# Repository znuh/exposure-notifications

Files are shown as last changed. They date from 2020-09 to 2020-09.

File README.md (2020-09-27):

# Exposure Notifications
Printed Circuit Boards for the Covid-19 Exposure Notifications Visualizer - 
[see this for more details](https://znu.nz/exposure_notifications-en)

To remake Exposure Notifications you need to get/make four things:
- a BBC micro:bit or Calliope Mini with the [microbit-corona-scanner](https://github.com/znuh/microbit-corona-scanner) installed
- a black 23x23cm RIBBA frame from IKEA
- the printed circuit board for the LEDs - see the leds/ directory of this repository
- the printed circuit board for the LED matrix controller - **either** matrixctl-v1 **OR** matrixctl-v2
  - matrixctl-v2 includes a socket for the micro:bit and a switching voltage regulator
  - matrixctl-v1 comes without a socket for the micro:bit and has no switching voltage regulator
  - v2 is more efficient and keeps the LED matrix driver cooler when more LEDs light up - therefore I recommend using v2

The printed circuit board designs are made with a **Nightly Development Build** of [KiCAD](https://kicad-pcb.org/).
If you want to open/edit them you also need a recent Nightly Development Build. If you just want to use the PCBs unmodified you can also use the gerber-files from the gerber-subdirectories.

## LED matrix board
The LED matrix board uses Würth 150141RV73100 LEDs. These are bicolor-LEDs but only the red LED is used.
The landing pads for the LEDs have been reduced to a minimum to hide the pads underneath the LEDs. All PCB tracks are on the back side of the PCB. 1206 0-Ohms resistors are used instead of vias to cross tracks.
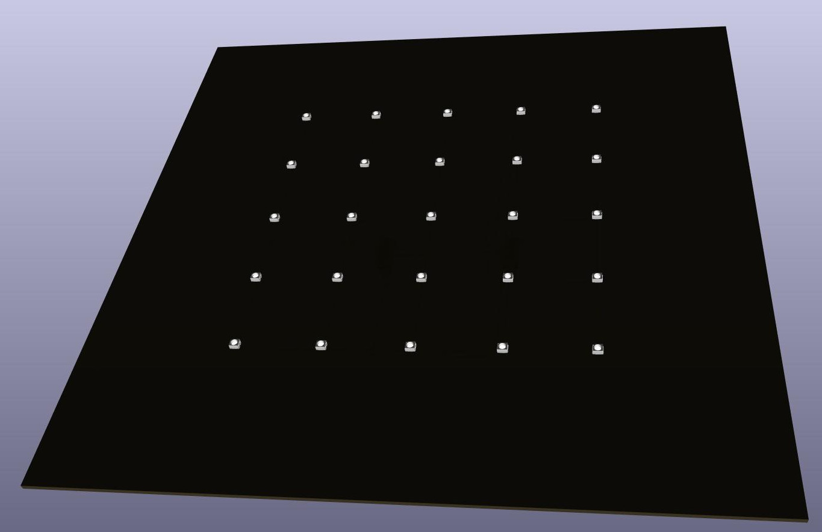
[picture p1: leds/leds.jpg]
LED matrix front side

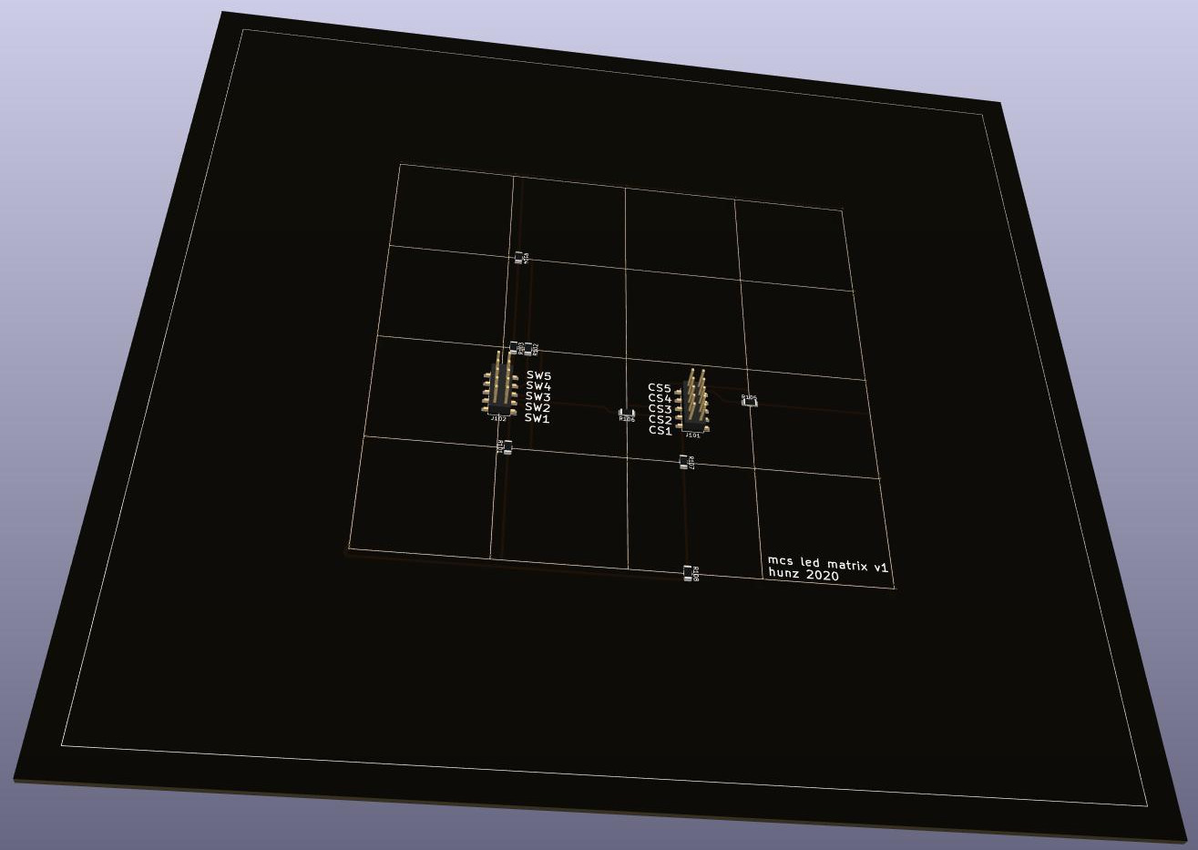
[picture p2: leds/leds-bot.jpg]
LED matrix back side


## matrixctl v2 board ##
The part number of the micro:bit socket is PIS-1240. The Micro-USB connector is a Molex 105017-0001. You can get these parts and all additional components from digi-key.

Following a recommendation from the IS31FL3738 datasheet the board includes a Tantalum Capacitor to avoid audible noise produced by ceramics capacitors through the [piezoelectric effect](https://product.tdk.com/en/contact/faq/31_singing_capacitors_piezoelectric_effect.pdf). Tantalum is a conflict resource. I've chosen a Kemet T495B336K010ATE450 because Kemet is a sane choice in general and their handling of the issue sounds ok.
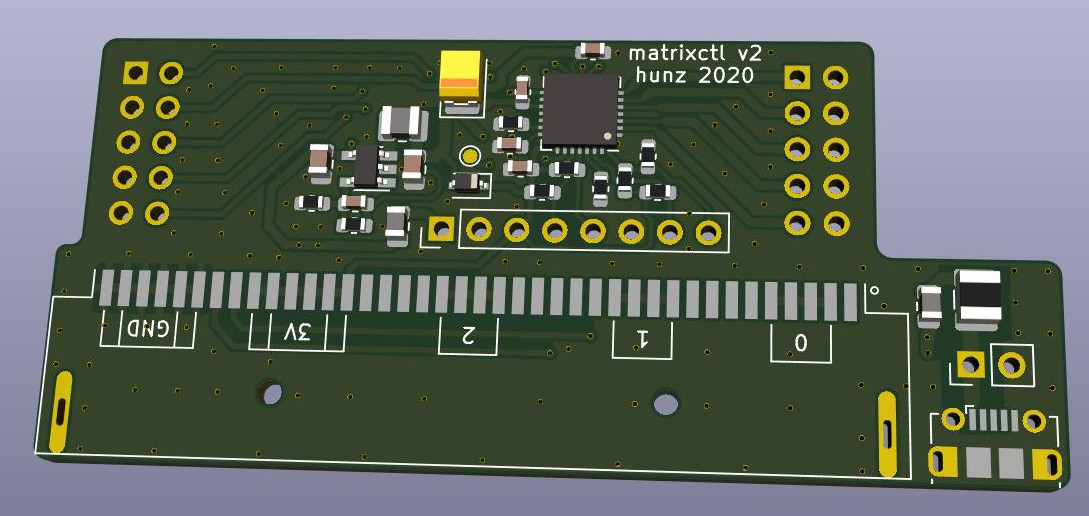
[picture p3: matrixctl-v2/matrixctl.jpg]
matrixctl v2

If you do not want to use the micro:bit socket you can also connect the micro:bit or a Calliope Mini to the pin header of the PCB. You need to connect I²C (SCL and SDA), 3V and GND.

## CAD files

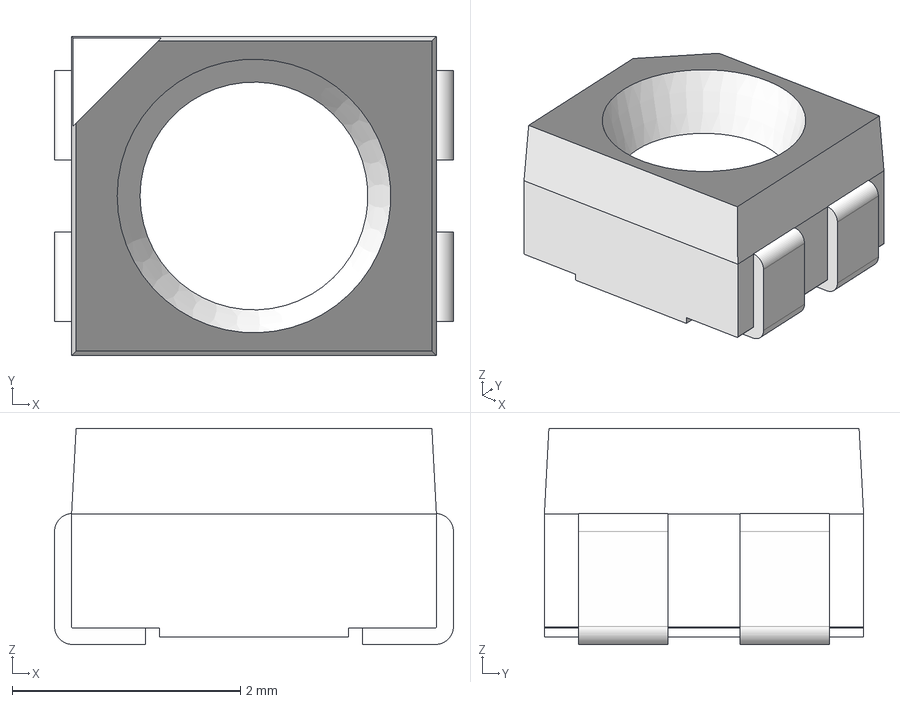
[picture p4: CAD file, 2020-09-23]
leds/3d/150141RB73100_Download_STP_WL-SBTW-3528_rev1.stp
3.50 x 2.80 x 1.90 mm
cover
housing
base x 2

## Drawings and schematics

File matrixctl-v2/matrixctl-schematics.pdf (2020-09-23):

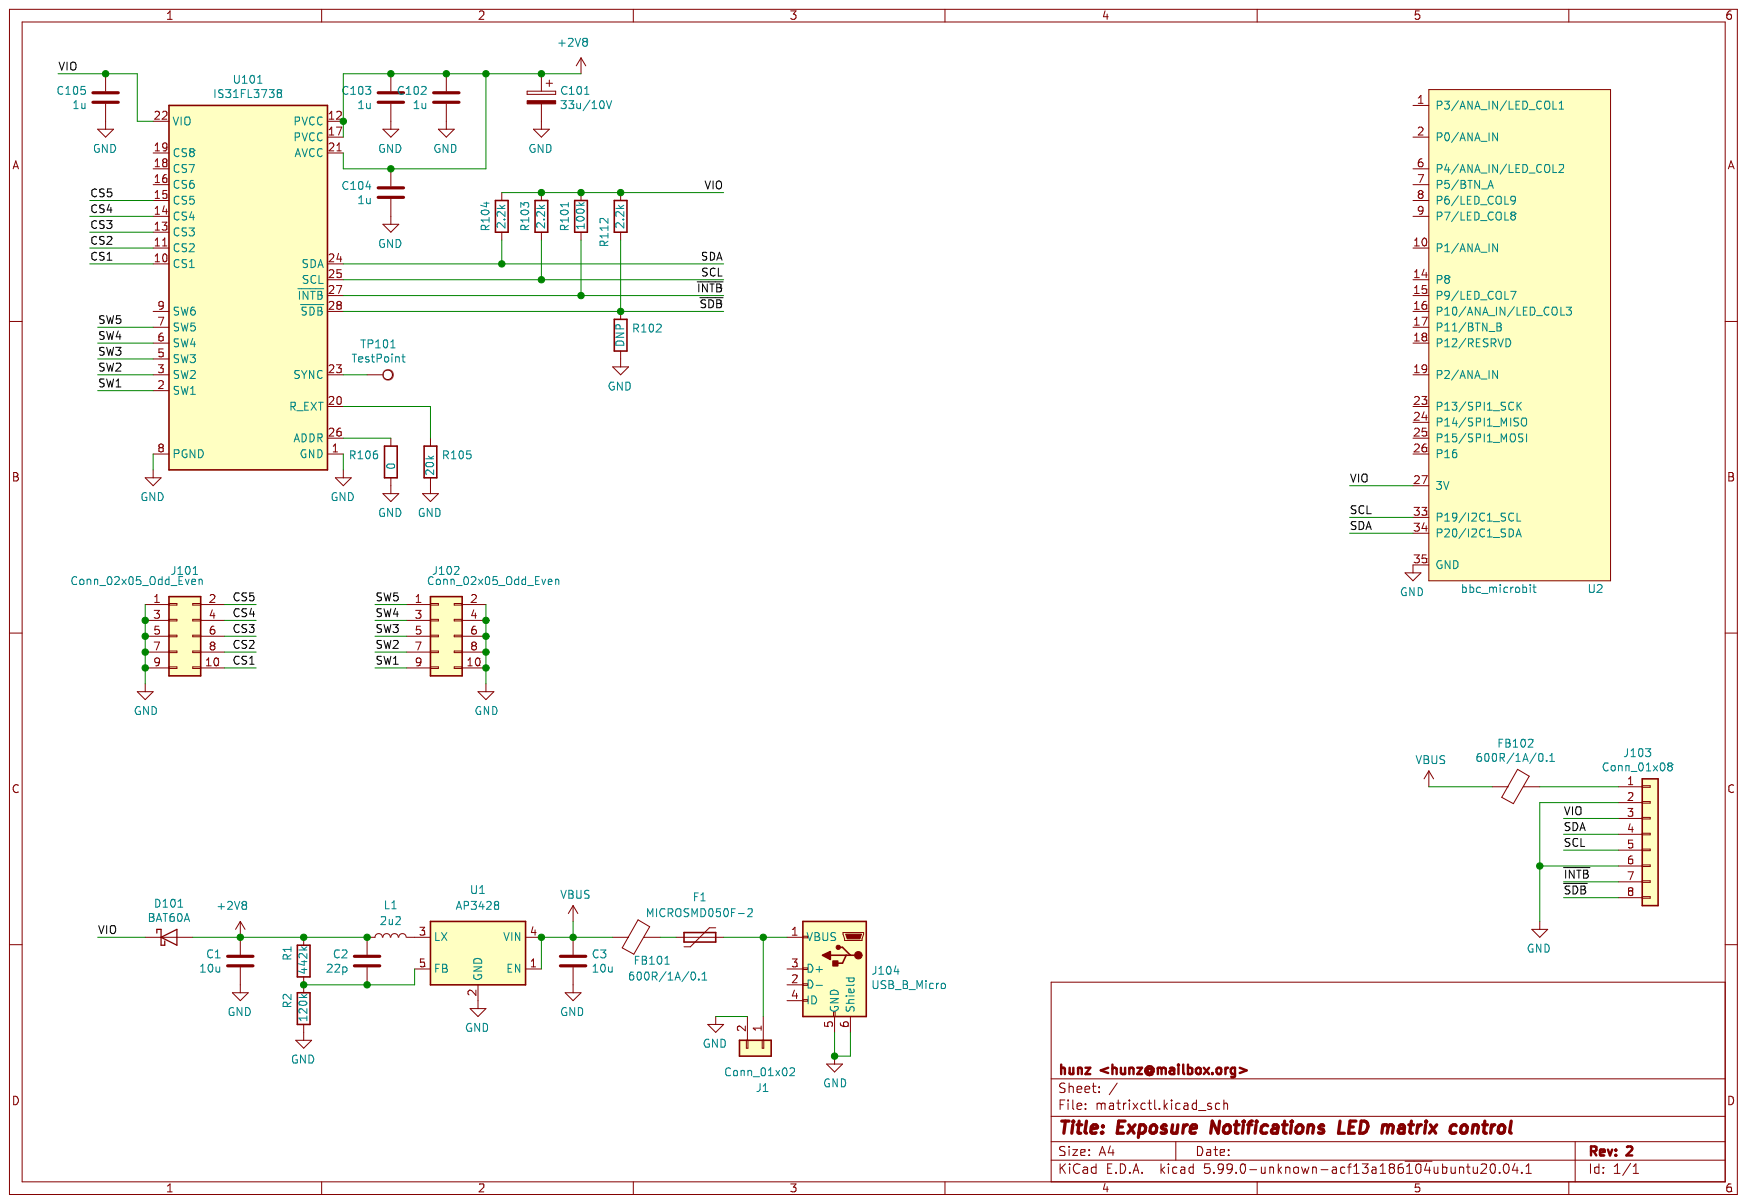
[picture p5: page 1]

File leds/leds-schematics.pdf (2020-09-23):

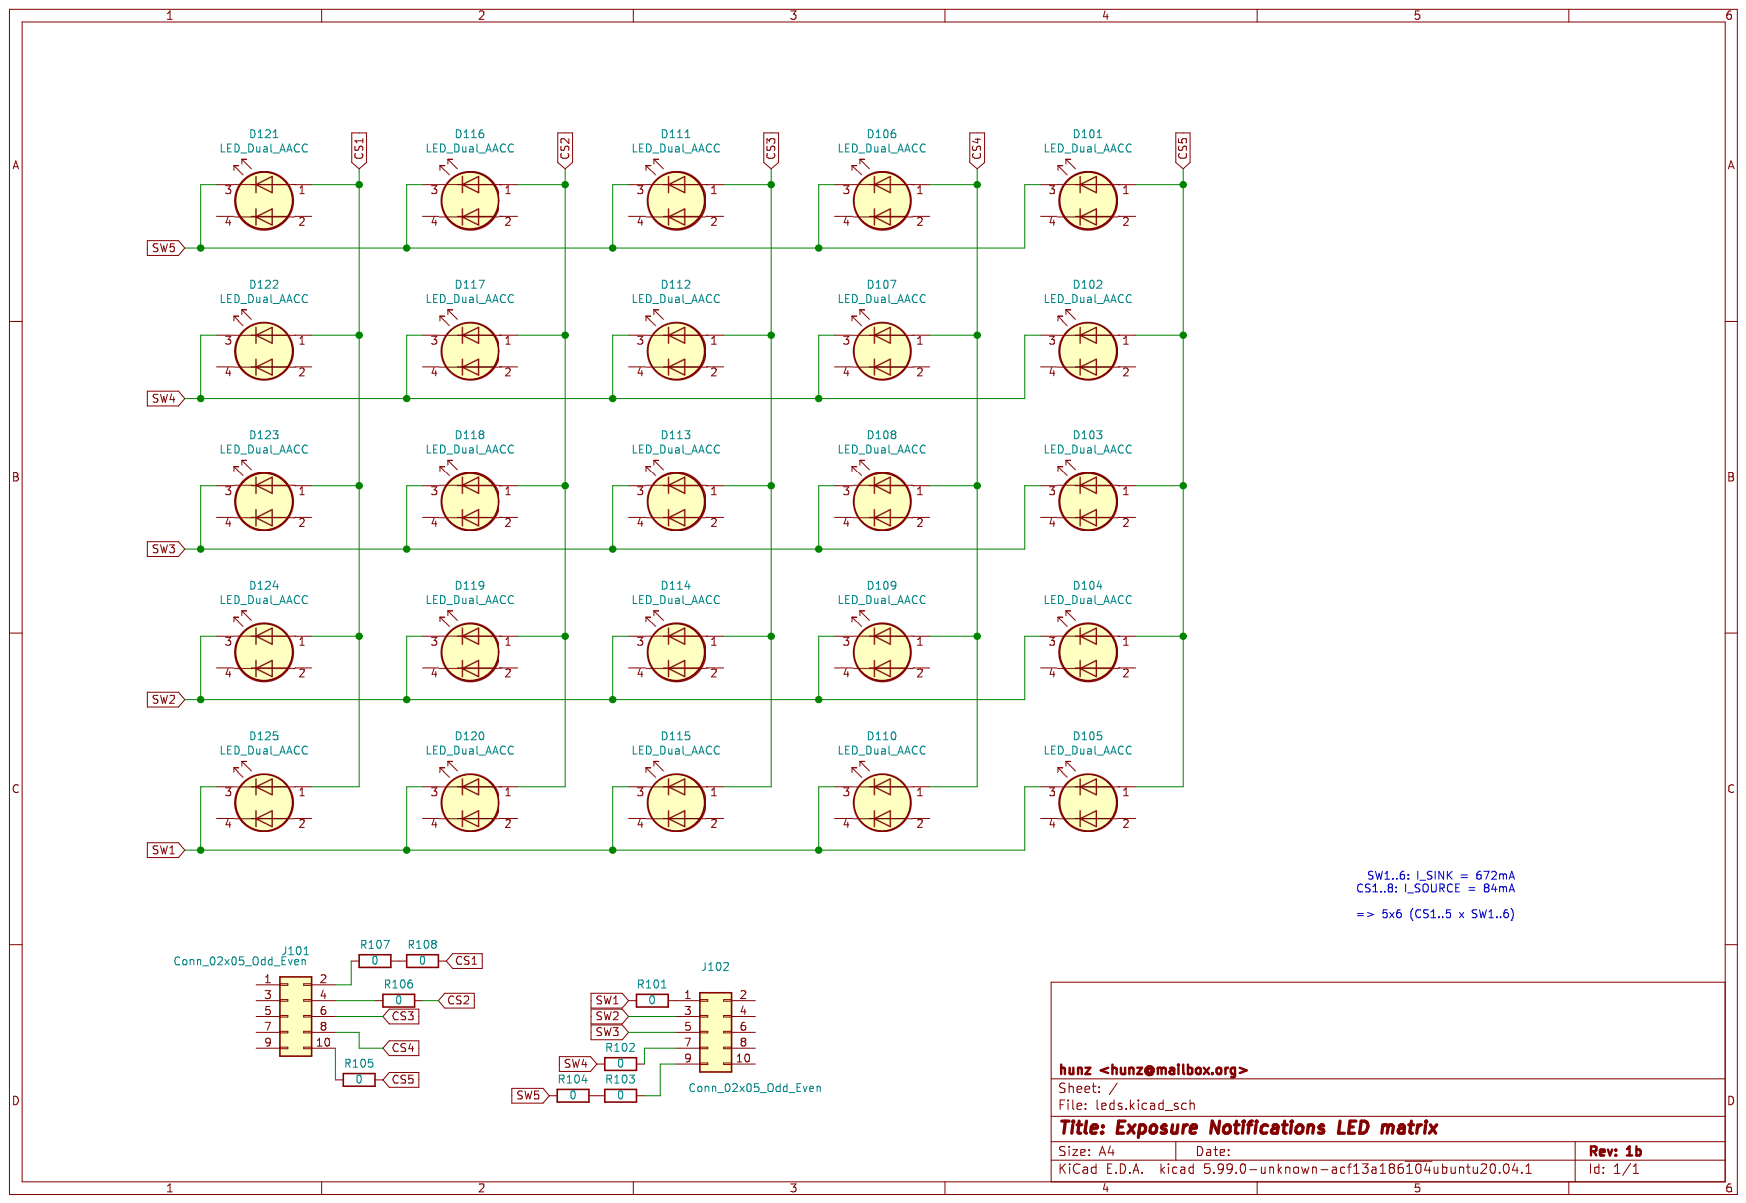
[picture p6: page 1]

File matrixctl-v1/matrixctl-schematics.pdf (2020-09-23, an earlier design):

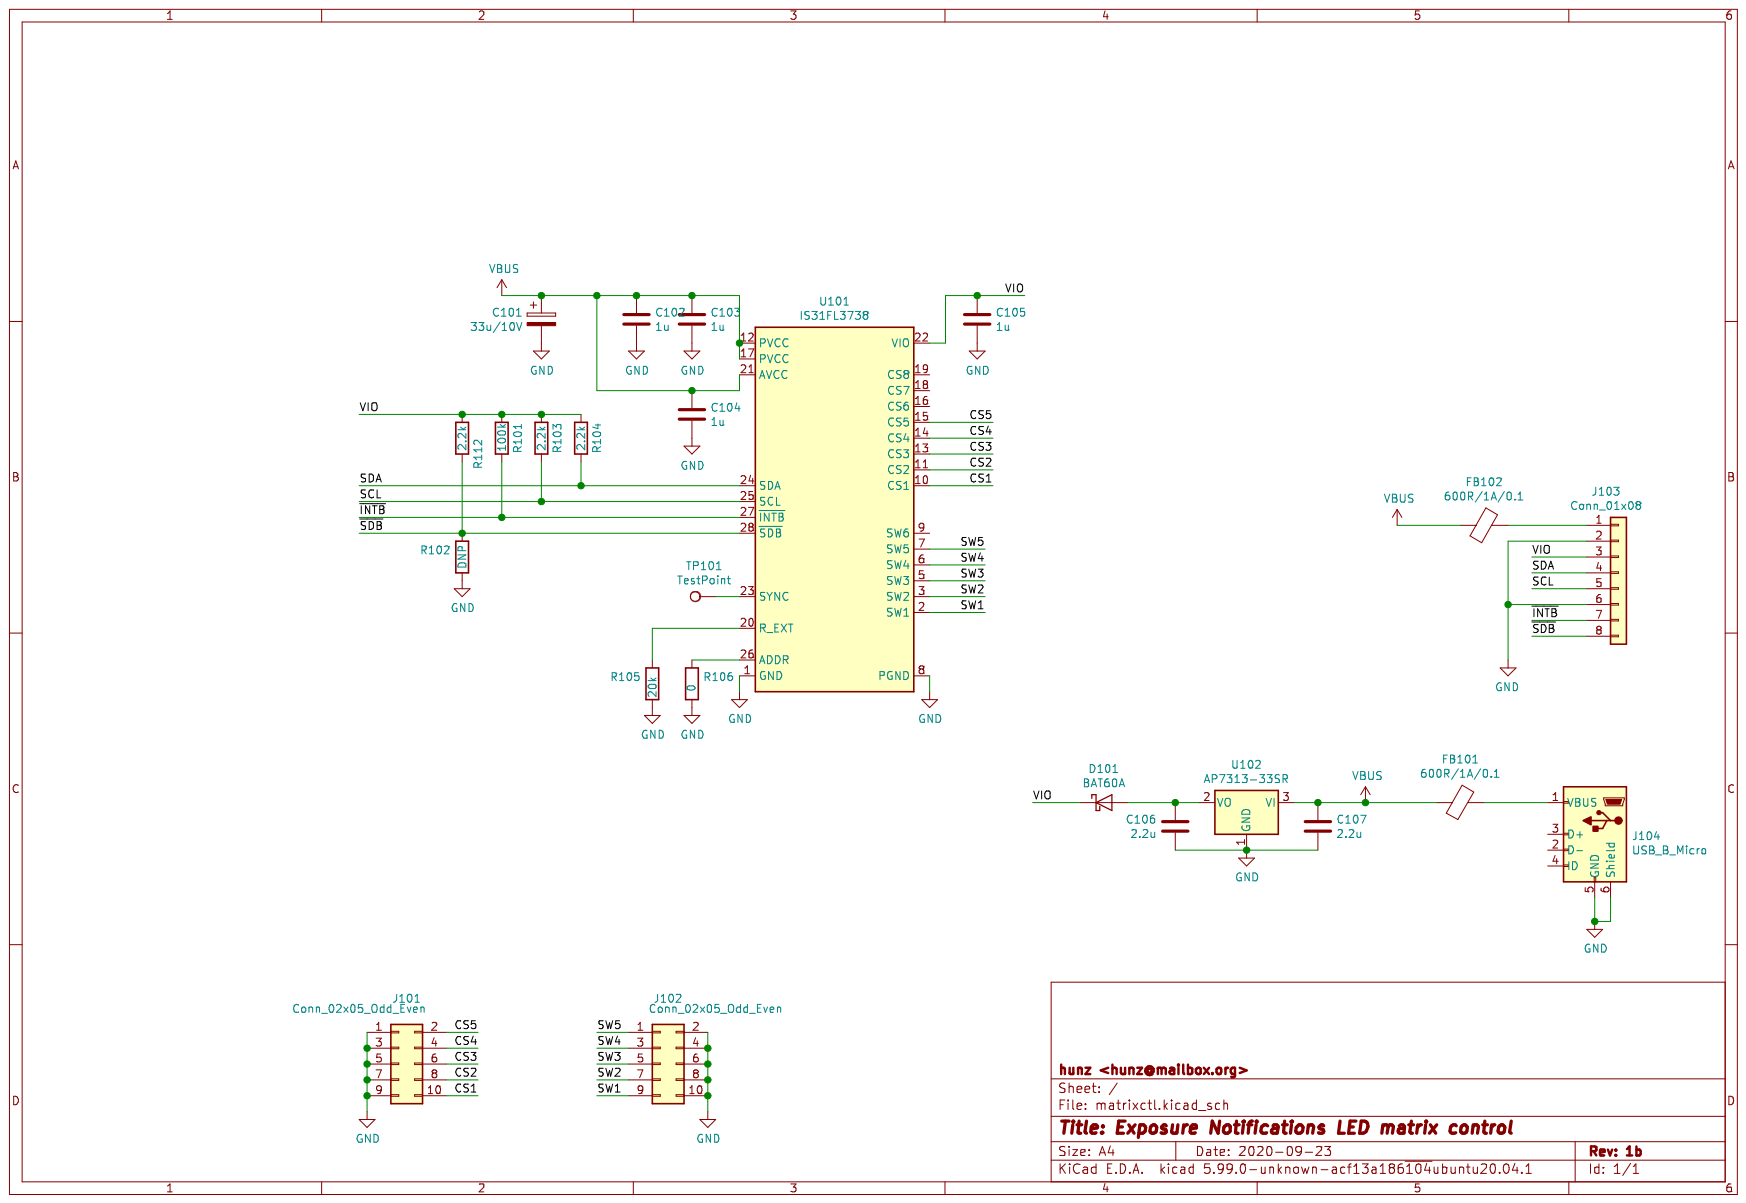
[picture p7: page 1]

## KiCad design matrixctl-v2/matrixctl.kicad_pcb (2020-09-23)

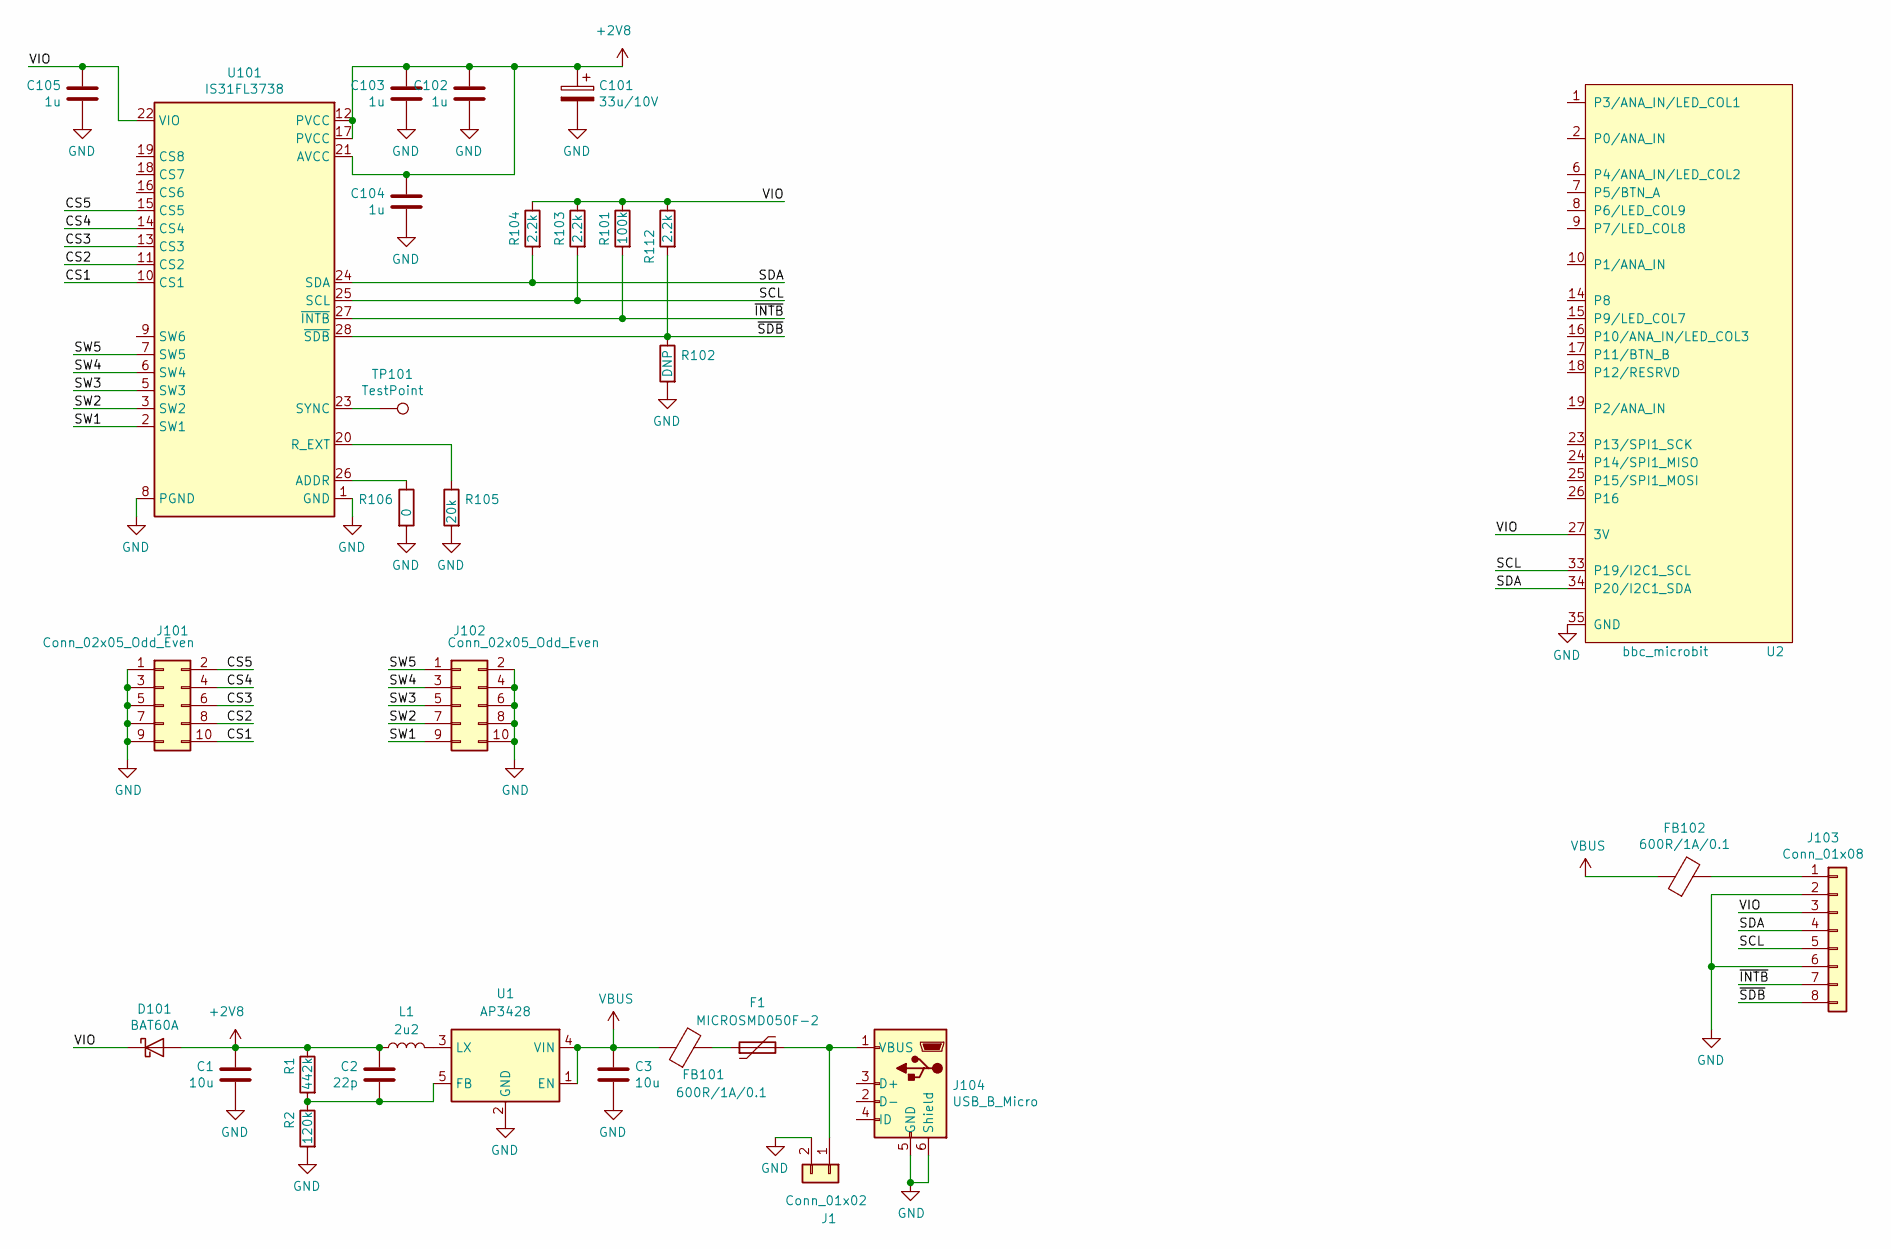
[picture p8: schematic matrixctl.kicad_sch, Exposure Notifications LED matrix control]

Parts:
C1, C3: 10u; C_0805_2012Metric
C2: 22p; C_0603_1608Metric
C101: 33u/10V; CP_EIA-3528-21_Kemet-B
C102, C103, C104, C105: 1u; C_0603_1608Metric
D101: BAT60A; D_SOD-323
F1: MICROSMD050F-2; Fuse_1210_3225Metric
FB101, FB102: 600R/1A/0.1; L_0805_2012Metric
J1: Conn_01x02; PinHeader_1x02_P2.54mm_Vertical
J101, J102: Conn_02x05_Odd_Even; PinSocket_2x05_P2.54mm_Vertical
J103: Conn_01x08; PinHeader_1x08_P2.54mm_Vertical
J104: USB_B_Micro; USB_Micro-B_Molex-105017-0001
L1: 2u2; L_1008_2520Metric
R1: 442k; R_0603_1608Metric
R2: 120k; R_0603_1608Metric
R101: 100k; R_0603_1608Metric
R102: DNP; R_0603_1608Metric
R103, R104, R112: 2.2k; R_0603_1608Metric
R105: 20k; R_0603_1608Metric
R106: 0; R_0603_1608Metric
TP101: TestPoint; TestPoint_Pad_D1.0mm
U1: AP3428; TSOT-23-5
U2: bbc_microbit; PIS-1240
U101: IS31FL3738; QFN-28-1EP_5x5mm_P0.5mm_EP3.5x3.5mm_ThermalVias

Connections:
+2V8: C1.1, C2.1, C101.1, C102.1, C103.1, C104.1, D101.2 (A), L1.2, R1.1, U101.12 (PVCC), U101.17 (PVCC), U101.21 (AVCC)
/CS1: J101.10, U101.10 (CS1)
/CS2: J101.8, U101.11 (CS2)
/CS3: J101.6, U101.13 (CS3)
/CS4: J101.4, U101.14 (CS4)
/CS5: J101.2, U101.15 (CS5)
/SCL: J103.5, R103.2, U2.33 (P19/I2C1_SCL), U101.25 (SCL)
/SDA: J103.4, R104.2, U2.34 (P20/I2C1_SDA), U101.24 (SDA)
/SW1: J102.9, U101.2 (SW1)
/SW2: J102.7, U101.3 (SW2)
/SW3: J102.5, U101.5 (SW3)
/SW4: J102.3, U101.6 (SW4)
/SW5: J102.1, U101.7 (SW5)
/VIO: C105.1, D101.1 (K), J103.3, R101.1, R103.1, R104.1, R112.1, U2.27 (3V), U2.28 (3V), U2.29 (3V), U2.30 (3V), U2.31 (3V), U2.32 (3V), U101.22 (VIO)
/~INTB: J103.7, R101.2, U101.27 (~INTB)
/~SDB: J103.8, R102.1, R112.2, U101.28 (~SDB)
GND: C1.2, C3.2, C101.2, C102.2, C103.2, C104.2, C105.2, J1.2, J101.1, J101.3, J101.5, J101.7, J101.9, J102.2, J102.4, J102.6, J102.8, J102.10, J103.2, J103.6, J104.5 (GND), J104.6 (Shield), R2.2, R102.2, R105.2, R106.2, U1.2 (GND), U2.35 (GND), U2.36 (GND), U2.37 (GND), U2.38 (GND), U2.39 (GND), U2.40 (GND), U101.1 (GND), U101.4 (PGND), U101.8 (PGND), U101.29 (PGND)
unnamed: C2.2, R1.2, R2.1, U1.5 (FB)
unnamed: F1.1, FB101.2
unnamed: F1.2, J1.1, J104.1 (VBUS)
unnamed: FB102.2, J103.1
unnamed: L1.1, U1.3 (LX)
unnamed: R105.1, U101.20 (R_EXT)
unnamed: R106.1, U101.26 (ADDR)
unnamed: TP101.1, U101.23 (SYNC)
unnamed: U2.2 (P0/ANA_IN), U2.3 (P0/ANA_IN), U2.4 (P0/ANA_IN), U2.5 (P0/ANA_IN)
unnamed: U2.10 (P1/ANA_IN), U2.11 (P1/ANA_IN), U2.12 (P1/ANA_IN), U2.13 (P1/ANA_IN)
unnamed: U2.19 (P2/ANA_IN), U2.20 (P2/ANA_IN), U2.21 (P2/ANA_IN), U2.22 (P2/ANA_IN)
VBUS: C3.1, FB101.1, FB102.1, U1.1 (EN), U1.4 (VIN)

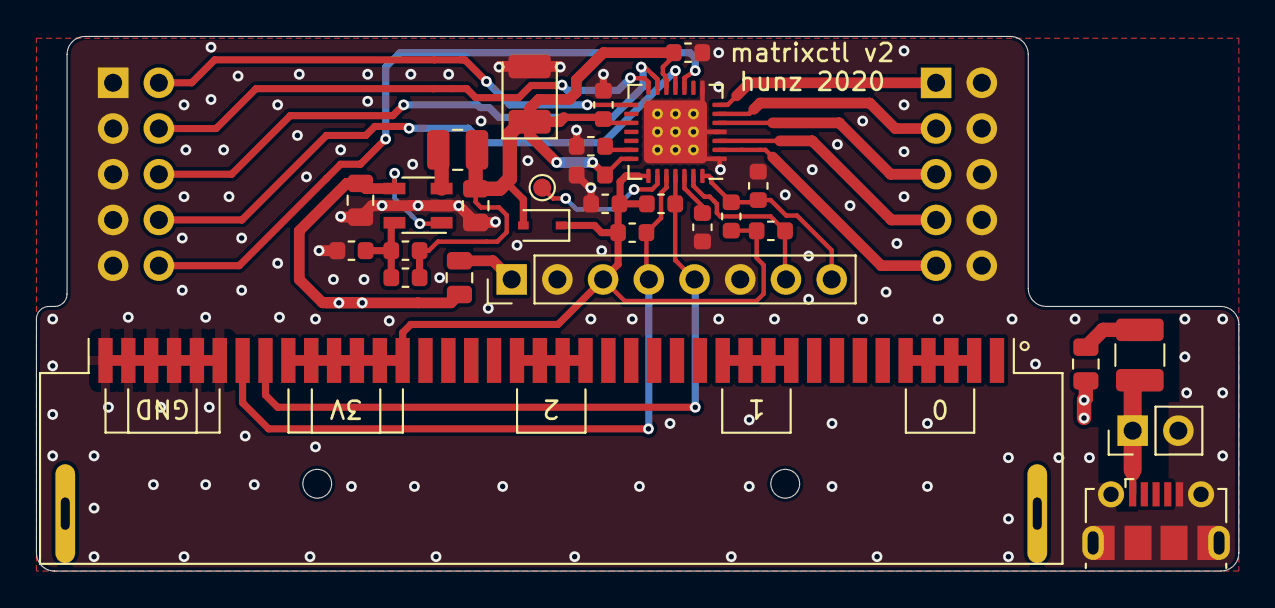
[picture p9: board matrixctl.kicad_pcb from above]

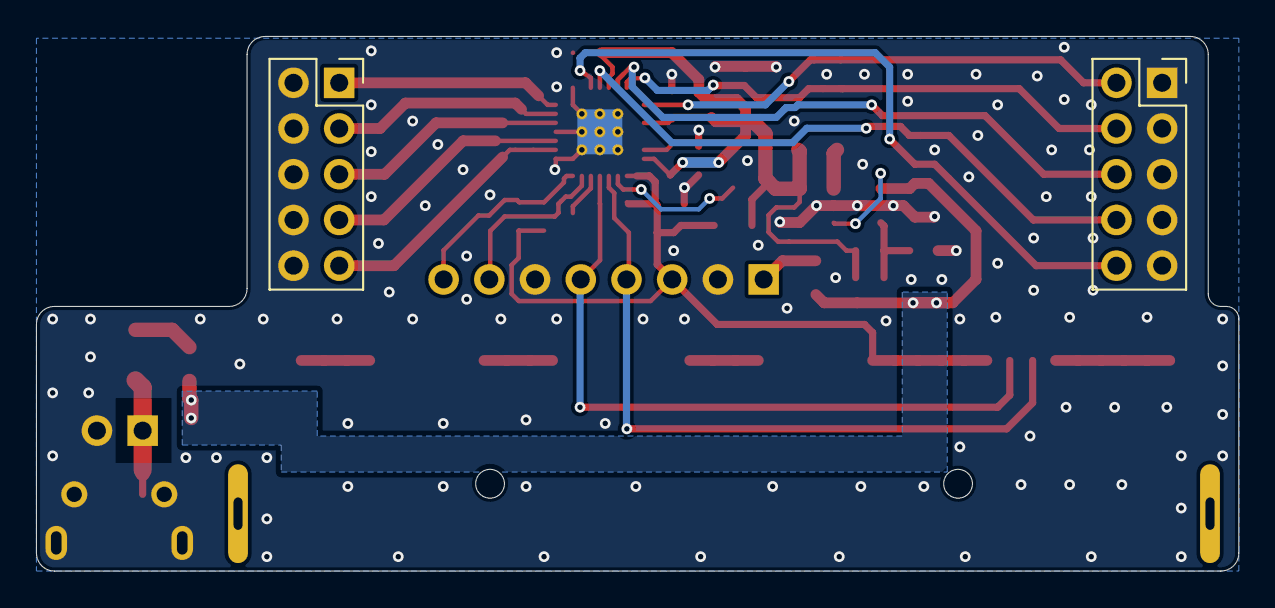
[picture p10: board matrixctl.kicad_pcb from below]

Board: 2 copper layers, 66.8 x 29.7 mm, 31 parts (2 on the bottom side), 29 nets.

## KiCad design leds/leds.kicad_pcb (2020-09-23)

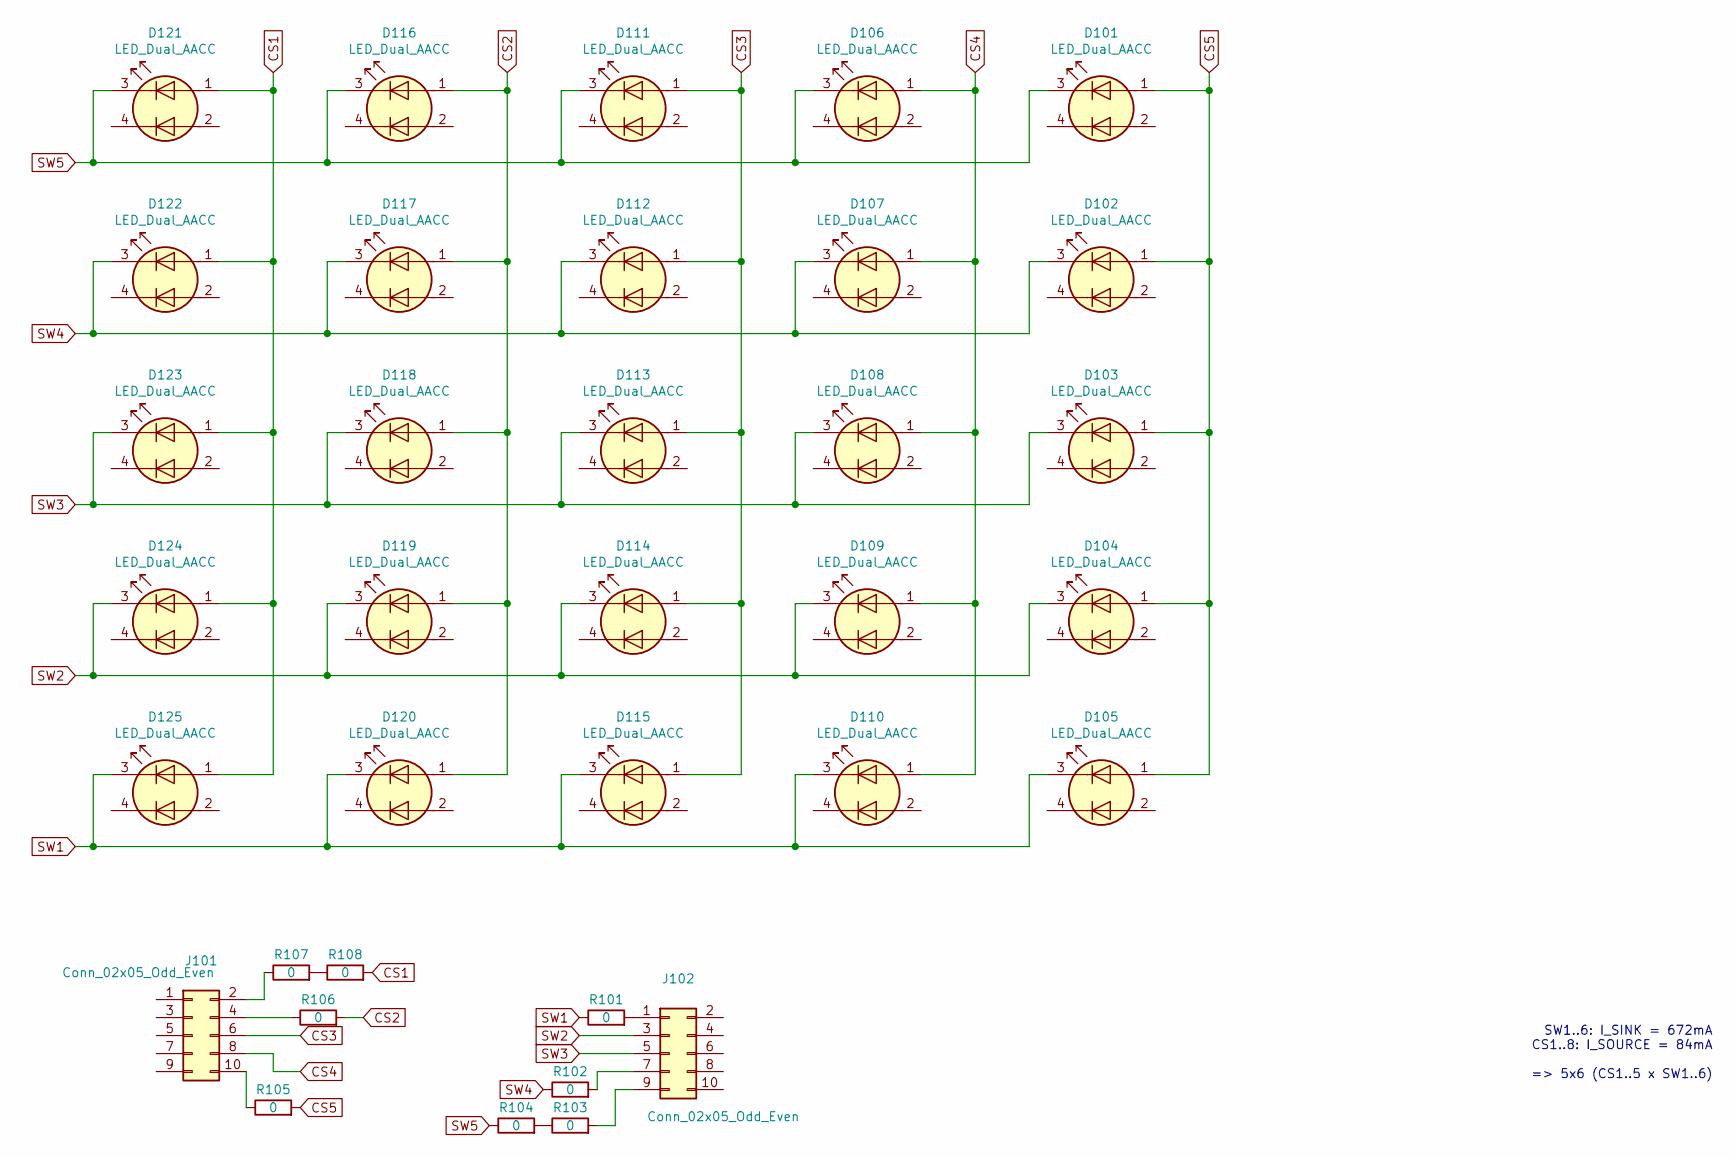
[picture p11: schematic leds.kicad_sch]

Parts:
D101, D102, D103, D104, D105, D106, D107, D108, D109, D110, D111, D112, D113, D114, D115, D116, D117, D118, D119, D120, D121, D122, D123, D124, D125: LED_Dual_AACC; Wuerth_150141RV73100
J101, J102: Conn_02x05_Odd_Even; PinHeader_2x05_P2.54mm_Vertical_SMD
R101, R102, R103, R104, R105, R106, R107, R108: 0; R_1206_3216Metric

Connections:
CS1: D121.1 (A1), D122.1 (A1), D123.1 (A1), D124.1 (A1), D125.1 (A1), R108.2
CS2: D116.1 (A1), D117.1 (A1), D118.1 (A1), D119.1 (A1), D120.1 (A1), R106.2
CS3: D111.1 (A1), D112.1 (A1), D113.1 (A1), D114.1 (A1), D115.1 (A1), J101.6
CS4: D106.1 (A1), D107.1 (A1), D108.1 (A1), D109.1 (A1), D110.1 (A1), J101.8
CS5: D101.1 (A1), D102.1 (A1), D103.1 (A1), D104.1 (A1), D105.1 (A1), R105.2
unnamed: J101.2, R107.1
unnamed: J101.4, R106.1
unnamed: J101.10, R105.1
unnamed: J102.1, R101.2
unnamed: J102.7, R102.2
unnamed: J102.9, R103.2
unnamed: R103.1, R104.2
unnamed: R107.2, R108.1
SW1: D105.3 (K1), D110.3 (K1), D115.3 (K1), D120.3 (K1), D125.3 (K1), R101.1
SW2: D104.3 (K1), D109.3 (K1), D114.3 (K1), D119.3 (K1), D124.3 (K1), J102.3
SW3: D103.3 (K1), D108.3 (K1), D113.3 (K1), D118.3 (K1), D123.3 (K1), J102.5
SW4: D102.3 (K1), D107.3 (K1), D112.3 (K1), D117.3 (K1), D122.3 (K1), R102.1
SW5: D101.3 (K1), D106.3 (K1), D111.3 (K1), D116.3 (K1), D121.3 (K1), R104.1

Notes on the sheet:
SW1..6: I_SINK = 672mA CS1..8: I_SOURCE = 84mA => 5x6 (CS1..5 x SW1..6)

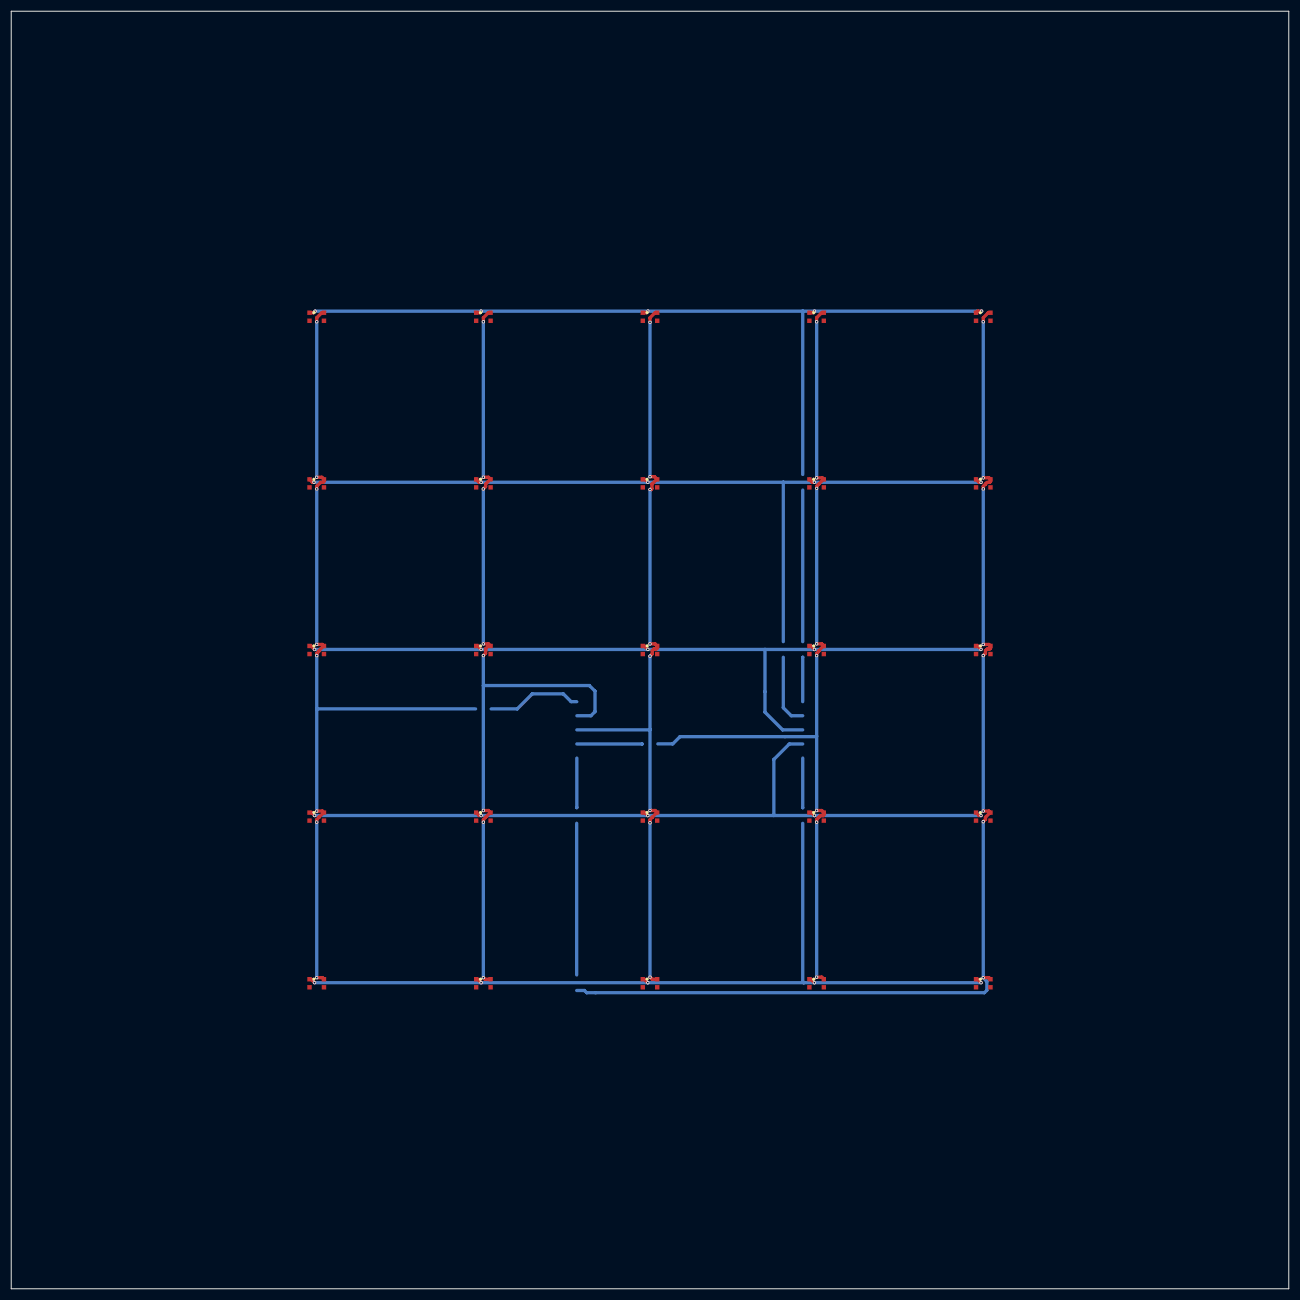
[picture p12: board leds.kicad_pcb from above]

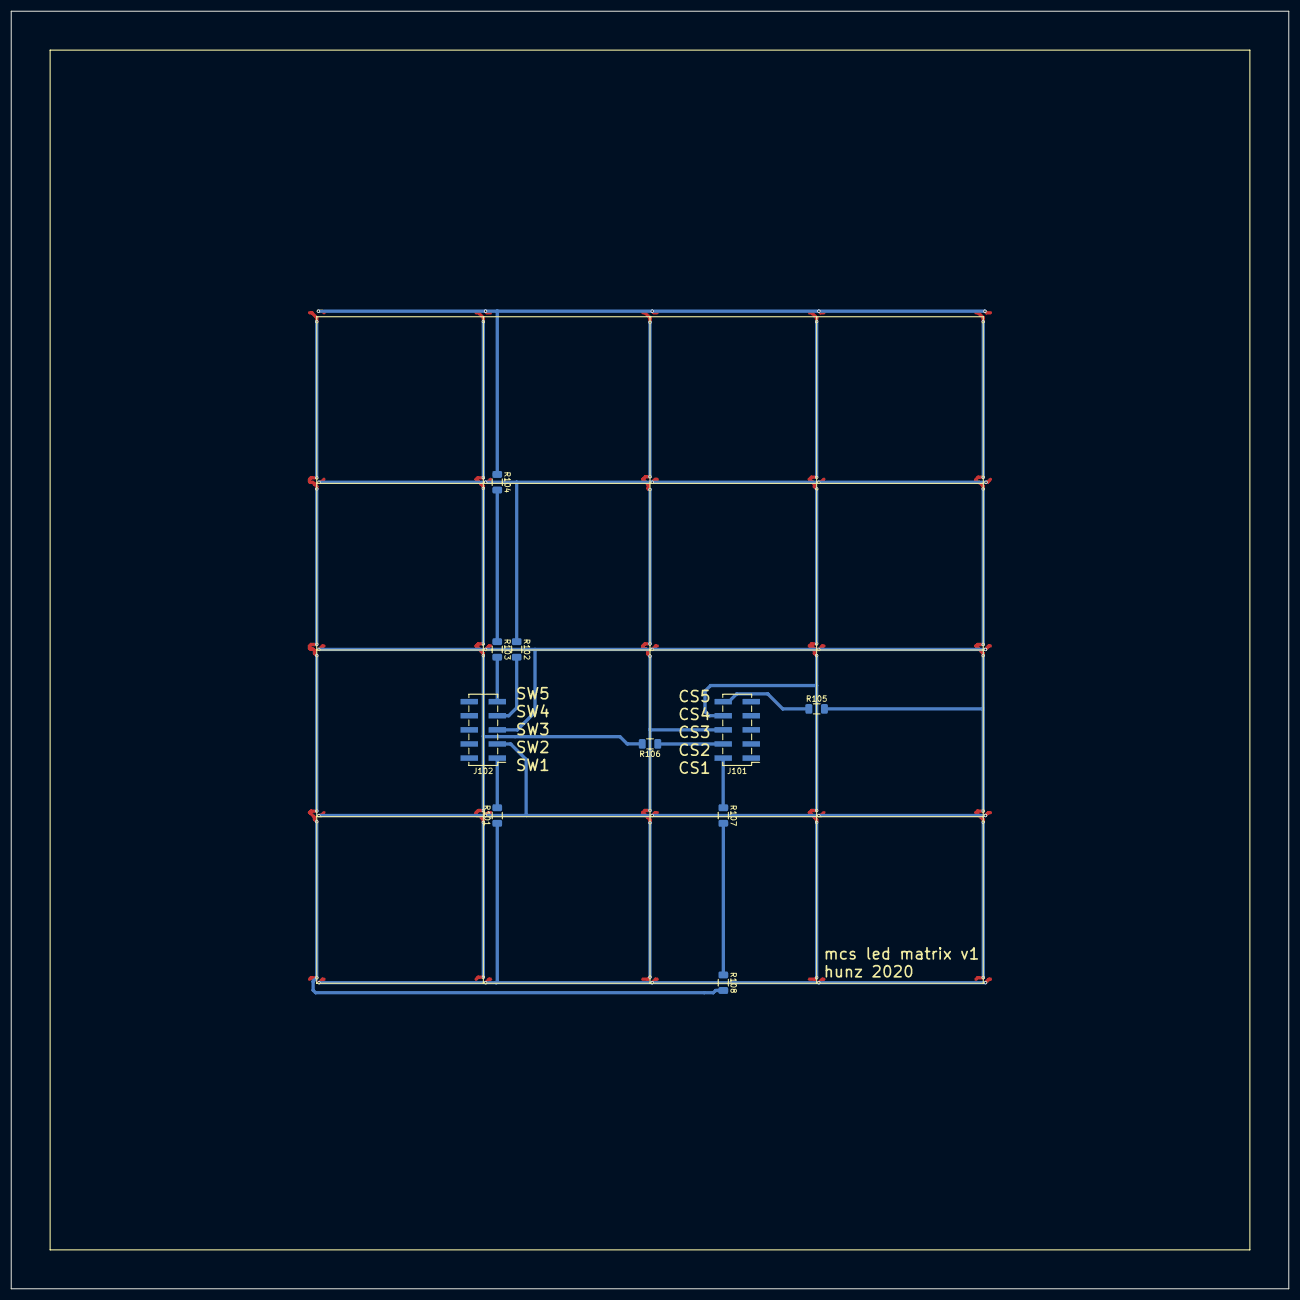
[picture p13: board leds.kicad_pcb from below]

Board: 2 copper layers, 230.0 x 230.0 mm, 35 parts (10 on the bottom side), 18 nets.

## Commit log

2020-09-23 initial import of matrixctl v2
    [matrixctl.kicad_pcb, matrixctl.kicad_sch]
2020-09-23 add gerber files
    [matrixctl-B_Cu.gbr, matrixctl-B_Mask.gbr, matrixctl-B_SilkS.gbr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]
2020-09-23 change gerber output path
    [matrixctl.kicad_pcb]
2020-09-23 initial import of LED matrix
    [150141RB73100_Download_STP_WL-SBTW-3528_rev1.stp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]
2020-09-23 change gerber path
    [leds.kicad_pcb]
2020-09-23 remove unused LEDs, add paste in gerber output
    [leds-B_Cu.gbr, leds-B_Paste.gbr, leds-B_SilkS.gbr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]
2020-09-23 add gerber and libs
    [matrixctl-B_Cu.gbr, matrixctl-B_Mask.gbr, matrixctl-B_SilkS.gbr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]
2020-09-23 actually it's v1
    [matrixctl.kicad_pcb]
2020-09-23 update gerber
    [matrixctl-B_Cu.gbr, matrixctl-B_Mask.gbr, matrixctl-B_SilkS.gbr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]
2020-09-23 add doc-fields in schematics, add PDFs of schematics
    [leds.kicad_sch, matrixctl.kicad_sch]
2020-09-23 C1 reduced from 22uF to 10uF to reduce risk of acoustic emmisions
    [matrixctl-B_Cu.gbr, matrixctl-B_Mask.gbr, matrixctl-B_SilkS.gbr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]
2020-09-23 add renderings of PCBs
